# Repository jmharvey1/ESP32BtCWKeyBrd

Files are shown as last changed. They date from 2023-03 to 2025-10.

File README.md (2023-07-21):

# ESP32 Bluetooth CW Keyboard & Decoder
___

A VS Code/PlatformIO project, Using ESPIDF's framework.
  
This ham radio project uses a generic Bluetooth Keyboard to send Morse Code (cw), and now using the audio out of your RX can decode CW too.
<p align="center">  
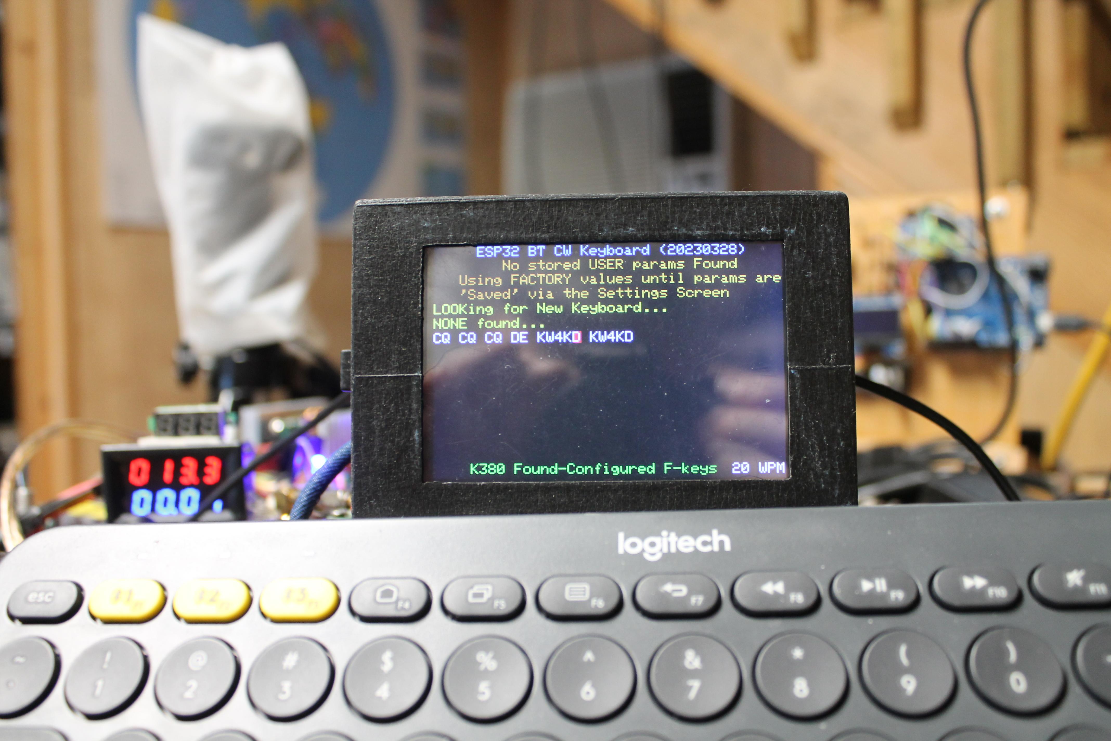
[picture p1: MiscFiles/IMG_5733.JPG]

</p>

<p dir="auto">For additional info, see YouTube video:
    <a href="https://youtu.be/Hb9m60LtSJw" rel="nofollow">https://youtu.be/Hb9m60LtSJw</a></p>

---
Main Hardware needed to replicate this project:
  
ESP32 WROOM dev board, (30 pin version)
  
3.5" TFT LCD Screen Display Module ILI9488 Board SPI Interface 480x320
  
Bluetooth Keyboard (Logitech K380, recommended)
  
___

Additional parts needed:
  
D4184 MOS FET (1)
  
HYDZ PIEZO Buzzer (1)

2n3904 (1)

2n3906 (1)

0.1ufd (3)

10ufd (1)
 
resistors 2.2K to 15K (4)
  
___
For those who want to bypass the source code, and just "flash" your ESP32, download the [ESPhomeFlasher](https://github.com/esphome/esphome-flasher/releases) and the [.bin file](https://github.com/jmharvey1/ESP32BtCWKeyBrd/blob/main/.pio/build/upesy_wroom/firmware.bin) found at these links.
  
Note: For me, using Linux Mint, the ESPhome-Flasher's 'Browse' button did NOT work. But placing the 'firmware.bin' file in the same folder as the flasher app, allowed me to just type the file name,"firmware.bin",
in the 'Firmware' cell.
  
A 2nd tip: Connect the ESP32 to your computer BEFORE launching the ESPhome-Flasher. 
___
A PCB for this project can be ordered from a board manufacturer, like [JLCPCB](https://jlcpcb.com/), using the gerber files found [Here](https://github.com/jmharvey1/ESP32BtCWKeyBrd/blob/main/MiscFiles/ESP32-BT-CW-KeyBrd_2023-03-16.zip).
  
A .PDF schematic for the PCB version of this project is [Here](https://github.com/jmharvey1/ESP32BtCWKeyBrd/blob/main/MiscFiles/ESP32-BT-CW-KeyBrd_Schematic.pdf)
  
If you have access to 3D printer, the [MiscFiles](https://github.com/jmharvey1/ESP32BtCWKeyBrd/tree/main/MiscFiles)
 folder contains “.stl” files for a simple case to host your completed project. 
___
Note: the PCB is currently not provisioned for the the decoder's audio input circuitry, nor is it documented in the MiscFiles folder.
But is super simple to add. It consists of pair of 10K voltage divider reisistors connected between gnd & the ESP32's 3.3V input, with the center tap connected to GPIO pin34 (ADC channel 6). A 0.1ufd DC blocking Capacitor is used to couple the external audio source (the RX's audio/speaker out) to GPIO pin 34.

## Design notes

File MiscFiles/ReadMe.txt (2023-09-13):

ESP32 Bluetooh KeyBoard user notes

***********************************************************************************
KeyBoard Encoder Notes:
Special Keys & their functions:
Keys that send special Morse Characters
1. “=”   <BT>
2. “+”	<KN>
3. ”>”	<AR>
4. ”<”	<AS>
5. ”%”	<SK>
6. All other unassigned keys (i.e. “{“, “]”,…) send 6 dits, CW error code

Special Functions:
1. cntrl+T	Generates continuous key down state. Press “cntrl+T” again (or another key) to stop.
2. Enter [pressed by itself] sends the "My Call" memory entry. (see settings screen)
3. “delete” Back space, to delete unsent buffered code.
4. Right Arrow	Same as F12.
5. Left Arrow Same as F1.  
6. Lshift+Enter” Send "Left Arrow" stored text plus Your call sign.
7. Cntrl+Enter” Send "Left Arrow" stored text.
8. "Esc"   Abort/dump outgoing text 	
10. Cntrl+S Go to settings Screen; Press Cntrl+S again to return to normal CW mode.(Note: No CW sent while in the "settings"mode); i.e., Default WPM. Call Sign, F2 memory
11. F1 Save up to ten characters (usually the DX call sign) to be sent when L. Shift (or Cntrl)+enter is pressed, Press F1 again to stop the "save"  mode (Note: status box in lower left is white while in "save" mode)
12. F2 Send stored F2 message
13. F3 Send stored F3 message
14. F4 Send stored F4 message
15. F12 suspend outgoing text; Press F12 again to resume sending outgoing text (Note: Status box is yellow while in "suspend" mode)

***********************************************************************************
CW Decoder Notes:
Special Keys & their functions:
1. Left & Rght Ctrl+d: index through CW decode modes
        Nrm (Normal)
        Bg1 (Bug 1)
        Bg2 (Bug 2)
        Bg3 (Bug 2 cootie keys)
2. Left Ctrl+f: index through select tone tune modes
        FF  (Fixed Frequency)
        AF  (Auto-Tune 500 to 900Hz)
3. Left Ctrl+G: index through 3 tone detect modes
        Nmf Fast Sample mode (4ms)
        Nms Slow Sample mode (8ms)
        Nmn Noisy signal mode (8ms sample period + damped Squech leveling)
4. Left Ctrl+P:  Plot On/off

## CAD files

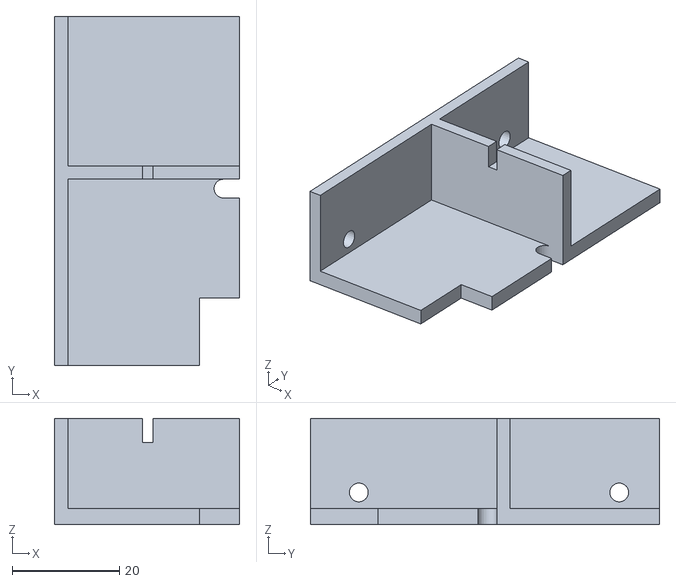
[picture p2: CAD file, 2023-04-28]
MiscFiles/ESP32BTKeyBrdSuprt.stl
34.5 x 65.0 x 19.8

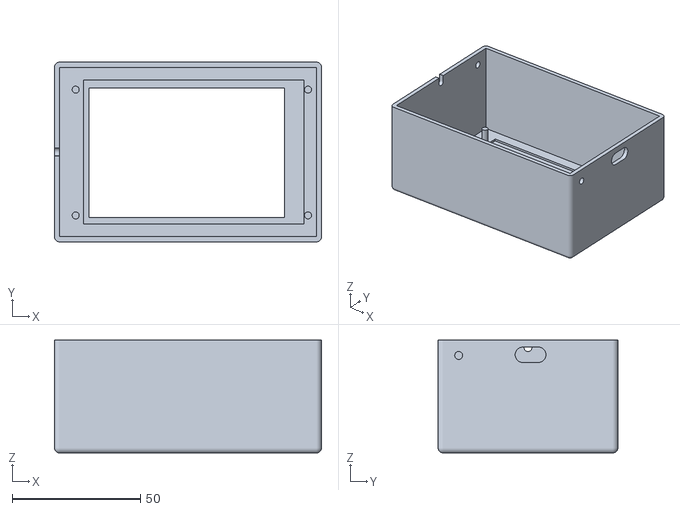
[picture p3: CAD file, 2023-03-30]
MiscFiles/ESP32BTKeyBrdCase.stl
104.0 x 70.0 x 44.0

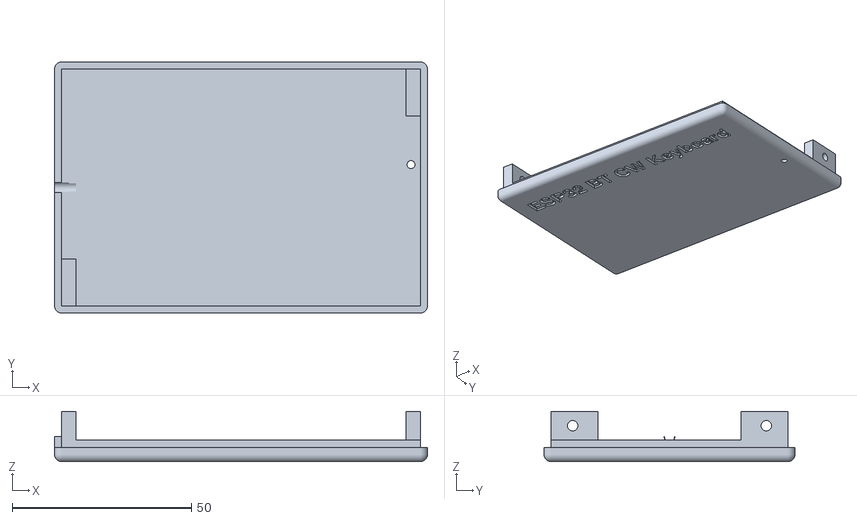
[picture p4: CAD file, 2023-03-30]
MiscFiles/ESP_BT_CW_KB_Backplate.stl
104.0 x 70.0 x 14.0

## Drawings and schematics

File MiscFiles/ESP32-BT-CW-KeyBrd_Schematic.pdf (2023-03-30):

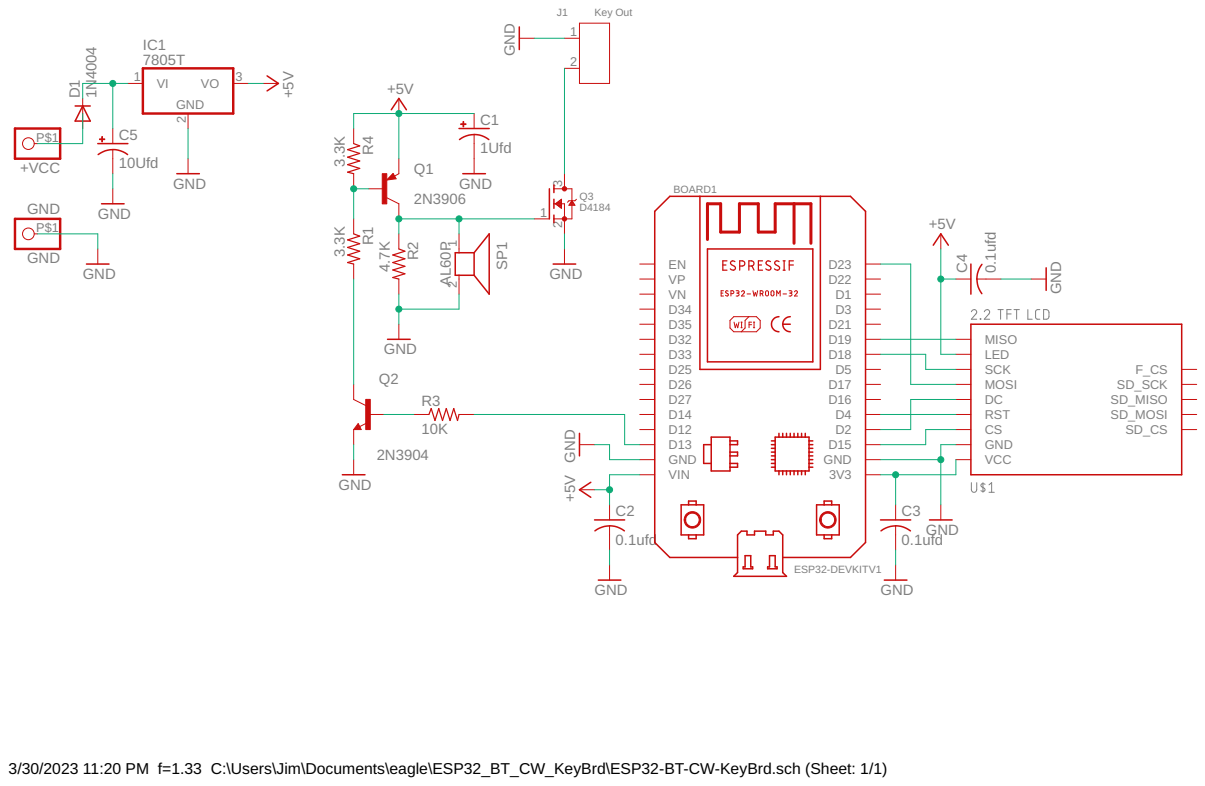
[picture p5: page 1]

3/30/2023 11:20 PM f=1.33 C:\Users\Jim\Documents\eagle\ESP32_BT_CW_KeyBrd\ESP32-BT-CW-KeyBrd.sch (Sheet: 1/1)

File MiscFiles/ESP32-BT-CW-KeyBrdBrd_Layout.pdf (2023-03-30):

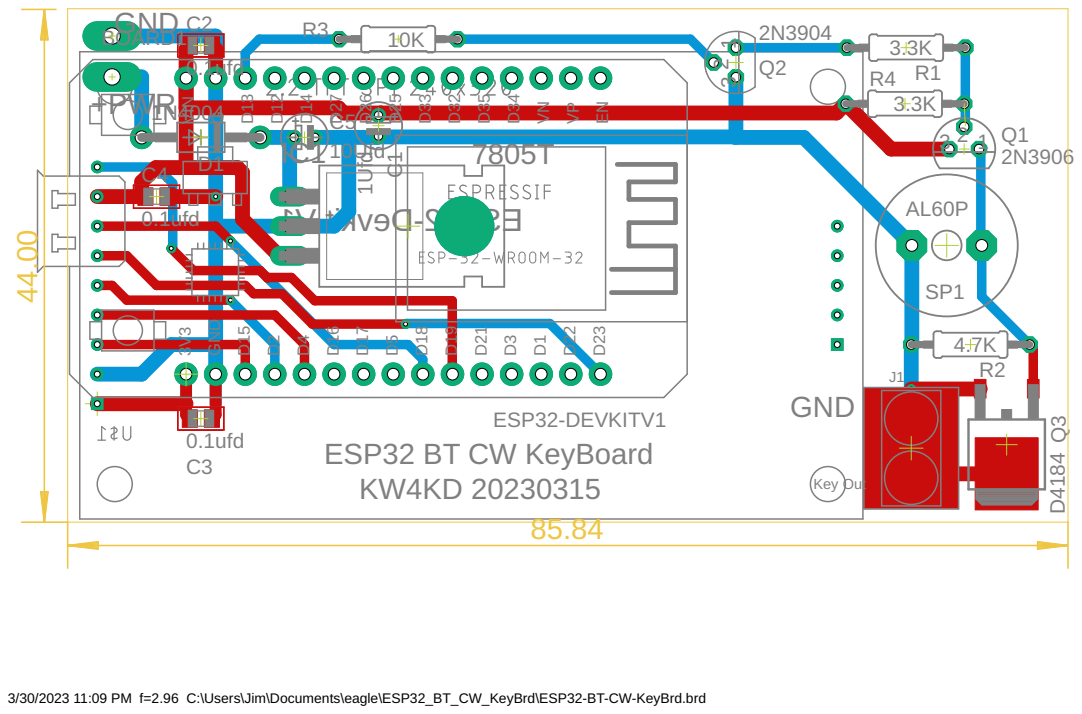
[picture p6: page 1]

3/30/2023 11:09 PM f=2.96 C:\Users\Jim\Documents\eagle\ESP32_BT_CW_KeyBrd\ESP32-BT-CW-KeyBrd.brd

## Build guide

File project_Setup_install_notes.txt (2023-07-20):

after copying files over,
run menuconfig,
& under Component config -> FreeRTos -> Kernel, enable configENABLE_BACKWARD_COMPATIBILITY
under component config -> bluetooth, check bluetooth
select/check Host Bluedroid-dual mode, & hid host
Controller (Enabled),
under Bluedriod options, check clasic bluetooth, & Classic BT hid
check Secure Simple Pairing, Bluetooth Low Energy
check IncludeGATT server module(GATTS)
check Enable BLE mult-connections. 
Leave all other selections to their default setting.
In the Dependant library 'TFT_eSPI', the following files have been modified to work in this hybrid enviroment:
1. User_Setup_Select.h
2. TFT_eSPI.h
3. TFT_eSPI.cpp
4. TFT_config. h
5. processors/TFT_eSPI32.h, ine 138, modified line to read "#include "SPIFFSJMH.h".
You can use MELD to see the differences. 
But probably easier to just copy these files from an already working project, with the same enviroment as this project
in the user_setup_select.h file, select the appropriate configuration for the display you're using. For SPI displays:
        #include <User_Setups/Setup42_ILI9341_ESP32.h>           // Setup file for ESP32 and SPI ILI9341 240x320
or
        #include <User_Setups/Setup21_ILI9488.h>           // Setup file for ESP32 and ILI9488 SPI bus TFT        
On TFTMsgBox.h, commnent or uncomment the "#define HiRes" (found @~ line 17) to match the resolution of the display being used.

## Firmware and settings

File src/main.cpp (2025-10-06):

/**
 * @file main.cpp
 * @brief ESP32 CW Decoder & Bluetooth Keyboard Main Application
 *
 * This file implements the main application logic for an ESP32-based CW (Morse code) decoder and Bluetooth keyboard interface.
 * It supports both Linux and Windows 10 environments and is designed to work with a TFT display (ILI9341 driver) and various
 * peripherals including ADC, Bluetooth HID keyboards, and FreeRTOS tasks.
 *
 * ## Features:
 * - Bluetooth keyboard pairing, scan, and event handling (supports Logitech K380 and others)
 * - Real-time CW decoding using Goertzel algorithm on ADC audio input
 * - Adjustable WPM (words per minute), auto-tune, and gain settings
 * - TFT display management for decoded text, status, and user interaction
 * - User-configurable memory messages (F2-F5), callsign, and settings stored in NVS
 * - Advanced Morse code parsing and error correction (AdvParser class)
 * - Multi-tasking using FreeRTOS for ADC processing, display updates, CW decoding, and post-processing
 * - Mutex and semaphore protection for shared resources
 * - Support for diagnostic and debug output
 * - Persistent user settings via NVS (Non-Volatile Storage)
 *
 * ## Main Components:
 * - **GoertzelHandler**: Processes ADC samples for tone detection and frequency measurement.
 * - **DisplayUpDt**: Updates the TFT display with decoded messages and status.
 * - **CWDecodeTask**: Main loop for CW decoding and error correction.
 * - **AdvParserTask**: Post-processing and advanced parsing of decoded Morse code.
 * - **ProcsKeyEntry**: Handles keyboard input, including special function keys and message sending.
 * - **NVS Read/Write Functions**: Manage persistent storage of user preferences and settings.
 * - **Timer ISRs**: Handle periodic display refresh and dot clock for outgoing Morse (CW) timing.
 *
 * ## Usage:
 * - On startup, initializes hardware, peripherals, and tasks.
 * - Pairs with a Bluetooth keyboard and waits for user input.
 * - Decodes incoming CW signals from ADC and displays results.
 * - Allows sending of pre-configured or custom messages via keyboard.
 * - User can access settings screen to configure preferences.
 *
 * ## Notable Definitions:
 * - `DF_t DFault`: Structure holding factory/user default settings.
 * - `TFTMsgBox tftmsgbx`: Handles display messaging.
 * - `CWSNDENGN CWsndengn`: Manages CW sending engine.
 * - `BTKeyboard bt_keyboard`: Bluetooth keyboard handler.
 * - `TxtNtryBox txtntrybox`: Text entry box for user input.
 *
 * ## Task Priorities:
 * - Goertzel Task: 5 (highest, for real-time ADC processing)
 * - CW Decode Task: 4
 * - Display Update Task: 3
 * - AdvParser Task: 2
 *
 * ## History:
 * - Extensive changelog documents ongoing improvements, bug fixes, and feature additions from 2020 through 2025.
 *
 * @author Jim (CW Decoder, ESP32 integration, enhancements)
 * @author Guy Turcotte (original BT-Keyboard code)
 * @copyright MIT License
 */
/* BT-Keyboard code (bt_keyboard.cpp) based on source code with the same file name &
   Copyright (c) 2020 by Guy Turcotte
   MIT License. Look at file licenses.txt for details.
*/
/*20230310 added logitech K380 configure function keys command */
/*20230317 added Memory F3 & F4 function keys */
/*20230328 moved to GitHub*/
/*20230405 reconfigued project files to run both on Linux & Windows 10*/
/*20230418 expanded send buffer from 160 to 400 charater (4 line to 10 dispaly lines)*/
/*20230429 Added code to CWSendEngn.cpp set character timing speed to a minimum of 15wpm*/
/*20230430 fixed crash issue related to changing speed while buffered code is being sent.*/
/*20230502 reworked WPM screen refresh & dotclk updated to timing period to avoid TFT display crashes.*/
/*20230503 Added code to bt_keyboard.cpp test for 'del' key presses an convert to hex code 0x2A*/
/*20230507 Reversed bavior of "Up" & "Down" Arrow keys & corrected dotclock startup timing to actually match the User stored WPM setting*/
/*20230607 DcoderCW.cpp CLrDCdValBuf() added other buffers & codevals to reset to stop decode artifacts of what the CWgen code was making during user send */
/*20230608 Enabled AutoTune indecoder default configuration */
/*20230609 Added code to the KEYISR (DcodeCW.cpp) to improve recovery/WPM tracking from slow to fast CW */
/*20230610 Remove '@'from the decoder dictionary */
/*20230615 reworked Goertzel.cpp & DcodeCW.cpp to better track the incoming WPM speed of the received station plus slight improvement in decoding CW @ > 35WPM As well at lower SNRs */
/*20230616 Added decoder mode & autotune to NVS eeprom; reworked startup (app_main) sequence to reduce crashes during 1st time pairing process */
/*20230617 To support advanced DcodeCW "Bug" processes, reworked dispMsg2(void) to handle ASCII chacacter 0x8 "Backspace" symbol*/
/*20230624 Minor tweaks to tone detect code & installed mutexs in bletooth callback to try to better manage SPI resource calls*/
/*20230701  Reworked Goertzel tone detection & added adjustable glitch detection; Also reworked Goertzel sample count code */
/*20230707 Added shortcuts (left/right Ctrl+g) user cntrolled gain setting; and reworked Glitch detection*/
/*20230708 reworked Glitch detection by adding a front end average keydown section to the tone detect routine; it now sets the glitch inteval*/
/*20230711 minor tweaks to concatenate processes (DcodeCW.cpp) to imporve delete character managment */
/*20230715 minor tweaks */
/*20230719 added "noreturn" patch to crash handler code and removed printf() calls originally in IRAM_ATTR DotClk_ISR(void *arg)*/
/*20230721 Moved project to github*/
/*20230727 Fixed Crash issue related to BT Keyboard sending corrupted keystroke data; fix mostly containg bt_keyboard.hid callback code*/
/*20230727 Reworked pairing code & mail code to avoid watchdog timer crashes*/
/*20230728 reworked code to improve pairing of multiple keyboard */
/*20230729 added calls to DcodeCW SetLtrBrk() & chkChrCmplt() to ensure that the letter break gets refreshed with each ADC update (i.e., every 4ms)*/
/*20230730 blocked the gudsig function to imporve noisy signal decoding */
/*20230731 Now launching the chkChrCmplt() strickly from goertzel/Chk4KeyDwn() task/routine*/
/*20230801 Added Short/Long (4ms/8ms) sample interval; User selectable via Ctrl+g */
/*20230804 Minor timing tweaks to  DecodeCW & Goertzel code*/
/*20230807 rewrote sloppy string check code for ESP32; See CcodeCW.cpp */
/*20230810 beta fix for crash linked to 1st time connection to previously 'paired keyboard. Requires stopping ADC sampling during the 'open' Keyboard event*/
/*20230811 beta2 fix for crash linked to 1st time connection to previously 'paired keyboard. Requires stopping ADC sampling during the 'open' Keyboard event*/
/*20230812 fix crash when using backspace key to delete unsent text */
/*20230814 changed ltrbrk timing for slow speed Bg2 mode */
/*20230815 revised Bg2 timing & rewote ltrbreak debugging output code */
/*20230818 fixed pairing crash linked to display SPI conflcit during BT pairing event */
/*20230916 Changed Auto-tune method; & reworked tone level detection; Added 3rd gain mode/setting */
/*20230918 Refined Auto-tune code; added autogain setting shift from slow to fast; added StrechLtrcmplt() to DcodeCW.cpp to better manage letterbreak detection */
/*20231103 reworked  DcodeCW.cpp, dit/dah decision tests & in Goertzel reworked auotsample rate detection code */
/*20231215 added DblChkDitDah() to DcodeCW.cpp, to further improve dit/dah decision tests */
/*20231217 reworked file references to match framework-espidf @ 3.50100.0 (5.1.0) */
/*20231221 minor tweek to DblChkDitDah (DeCodeCW.cpp) routine to improve resolving dits from dahs*/
/*20231229 More tweaks to bug2 letter break code (DeCodeCW.cpp)*/
/*20240101 More tweaks to bug2 letter break code (DeCodeCW.cpp)*/
/*20240103 Modified extented sysmbolset timing to only effect Bg1 mode*/
/*20240110 Added Advparser Class */
/*20240112 Continued development of Advparser Class */
/*20240115 Continued development/enhancement of Advparser Class */
/*20240117 added Dcode4Dahs() to AdvParser class; parses 4 dahs into "TO" or "OT", "MM" also a possible result */
/*20240119 added test for paddle/keybrd by finding all dahs have the same interval;*/
/*20240120 reworked DitDahBugTst() method to better detect bug vs paddle/keyboard signals plus minor tweaks to bug rule set*/
/*20240122 revised AdvParser.cpp DitDahSplitVal averaging algorithm to be based on last 30 symbol set elements*/
/*20240123 AdvParser.cpp - Added letterbrk bug test "2", to look for lttrbk based on "long" dah*/
/*20240124 DcodeCW.cpp added requirement that Key up & down arrays match in length before attempting to do a post reparse of the last word captured*/
/*20240129 AdvParser.cpp - improved method for calculating DitIntrvlVal + other tweaks to bug parsing rules*/
/*20240201 AdvParser.cpp - Added Straight Key Rule Set & Detection; Revised Bug1 RS dit & dah runs parsing*/
/*20240202 AdvParser.cpp - Added Bg1SplitPt & refined Bug1 "Dah run" code*/
/*20240203 Added initialization values to AdvParser to imporve 1st decode/parsing results*/
/*20240204 added GetState method to CWSndEngn class; primarily to notify decoder/Goertzl side to go into 'standby/sleep' mode*/
/*20240205 added WrdBrkVal property Advparser Class + changes to Bug1 & DitDahBugTst*/
/*20240206 added StrchdDah property to Advparser Class*/
/*20240207 ammended 'Advparser.AdvSrch4Match' method for setting up 'follow on' search*/
/*20240208 AdvParser.cpp, reworked 'LstLtrBrkCnt' management to better track the number of keyevents since the last letterbreak event */
/*20240210 created new class method 'Advparser.SrchAgn()'*/
/*20240211 Made chnges to AdParser.cpp, mainly to align dit/dah decision points with the ruleset in play */
/*20240215 AdParser.cpp - More minor tweaks to Bug1 Rule set & DitDahBugTst()*/
/*20240216 AdParser.cpp - Added 'FixClassicErrors()' method*/
/*20240220 AdParser.cpp - added 'SloppyBgRules()' method. Plus numerous changes to integrate this rule set into the existing code */
/*20240223 numerous 'tweaks' to AdParser.cpp, mostly to better delineate between different key types*/
/*20240225 AdParser.cpp - more 'tweaks' to bug2 & sloppybug rule sets */
/*20240225 setup post parsing to run as a task (AdvParserTask)*/
/*20240227 reworked AdvParserTask() & setup to run on core 1; reworked AdvParser.cpp - GetMsgLen(void), FixClassicErrors(void), & SloppyBgRules(int& n)*/
/*20240301 AdParser.cpp -Changed BG2 dah run to detect letterbreak on UnitIntvrlx2r5; chages to SetSpltPt()*/
/*20240304 Reworked deployment of mutex to reduce code crashes linked to keyboard entries*/
/*20240307 AdParser.cpp Added SrchEsReplace() function & and simplified the code in FixClassicErrors()*/
/*20240309 AdParser.cpp - Moved straight key test ahead of sloppy test*/
/*20240309 AdParser.cpp - Mostly tweaks in FixClassicErrors() code */
/*20240313 AdParser.cpp - rewrote FixClassicErrors() to sequence through SrchRplcDict[] array to test for mangled character strings */
/*20240315 AdvParser.cpp - rewrote FixClassicErrors() to use a 'for' loop to sequence through the SrchRplcDict[]*/
/*20240317 changed task management mainly through priority level assignments; reworked AdParser.SetSpltPt() method to better handle cootie type keying*/
/*20240322 expanded SrchRplcDict[] to 192 entries */
/*20240323 expanded SrchRplcDict[] to 212 entries*/
/*20240330 expanded SrchRplcDict[] to 289 entries*/
/*20240405 expanded SrchRplcDict[] to 329 entries*/
/*20240408 expanded SrchRplcDict[] to 346 entries*/
/*20240411 expanded SrchRplcDict[] to 400 entries*/
/*20240414 expanded SrchRplcDict[] to 413 entries*/
/*20240420 expanded SrchRplcDict[] to 472 entries*/
/*20240427 expanded SrchRplcDict[] to 526 entries*/
/*20240502 added entries 527 - 586 to  SrchRplcDict[] (superslopy) */
/*20240504 expanded SrchRplcDict[] to 634 entries*/
/*20240518 expanded SrchRplcDict[] to 682 entries*/
/*20240519 AdvParser.cp Added glitch detection*/
/*20240522 Goertzel.cpp, added auto glitch detection,to support post parser (AdvParser.cpp)*/
/*20240601 Minor tweaks to AdvParser.cpp to improve rule set selection & adds SrchRplcDict[]*/
/*20240608 Expanded SrchRplcDict[] to 731 entries*/
/*20250930 restructed to work with framework-espidf@~3.50202.0 */
/*20251006 bt_keyboard.cpp reworked keyboard pairing & reconnect */

#include "sdkconfig.h" //added for timer support
#include "globals.h"
#include "main.h"
#include "bt_keyboard.hpp"
#include <esp_log.h>
#include <iostream>
//#include "esp32-hal-spi.h"
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
void app_main()
{
  /*uncomment the following for diagnostic testing of host HID connection/pairing to keyboard*/
  // Exmpl_main();
  // while(1){
  //   vTaskDelay(1000 / portTICK_PERIOD_MS);
  // }
  ModeCnt = 0;
  static const char *TAG = "TASK Config";
  // Configure pin
  gpio_config_t io_conf;
  io_conf.intr_type = GPIO_INTR_DISABLE;
  io_conf.mode = GPIO_MODE_OUTPUT;
  io_conf.pin_bit_mask = (1ULL << KEY);
  io_conf.pull_down_en = GPIO_PULLDOWN_DISABLE;
  io_conf.pull_up_en = GPIO_PULLUP_DISABLE;
  gpio_config(&io_conf);
  digitalWrite(KEY, Key_Up); // key 'UP' state
  state_que = xQueueCreate(state_que_len, sizeof(uint8_t));
  /*create DisplayUpDate Task*/
  xTaskCreatePinnedToCore(DisplayUpDt, "DisplayUpDate Task", 8192, NULL, 3, &DsplUpDtTaskHandle, 0);
  vTaskSuspend( DsplUpDtTaskHandle);

  /*Selected 2092 based on results found by using uxTaskGetStackHighWaterMark( NULL ) in AdvParserTask*/
  xTaskCreatePinnedToCore(
      AdvParserTask, /* Function to implement the task */
      "AdvParser Task", /* Name of the task */
      4096,  /* Stack size in words */
      NULL,  /* Task input parameter */
      2,  /* Priority of the task */
      &AdvParserTaskHandle,  /* Task handle. */
      1); /* Core where the task should run */
  if (AdvParserTaskHandle == NULL)
    ESP_LOGI(TAG, "AdvParser Task handle FAILED");

  vTaskSuspend( AdvParserTaskHandle );
  
  xTaskCreatePinnedToCore(
      CWDecodeTask, /* Function to implement the task */
      "CW Decode Task", /* Name of the task */
      8192,  /* Stack size in words */
      NULL,  /* Task input parameter */
      4,  /* Priority of the task */
      &CWDecodeTaskHandle,  /* Task handle. */
      0); /*Core 0 or 1 */
  
  if (CWDecodeTaskHandle == NULL)
    ESP_LOGI(TAG, "CW Decoder Task handle FAILED");

  xTaskCreate(GoertzelHandler, "Goertzel Task", 8192, NULL, 5, &GoertzelTaskHandle); // priority used to be 3
  if (GoertzelTaskHandle == NULL)
    ESP_LOGI(TAG, "Goertzel Task Task handle FAILED");

  /*Setup Software Display Refresh/Update timer*/
  DisplayTmr = xTimerCreate(
      "Display-Refresh-Timer",
      33 / portTICK_PERIOD_MS,
      pdTRUE,
      (void *)1,
      DsplTmr_callback);

  memset(result, 0xcc, (SOC_ADC_DIGI_RESULT_BYTES * Goertzel_SAMPLE_CNT)); // 1 byte for the channel # & 1 byte for the data
  mutex = xSemaphoreCreateMutex();
  // ADC_smpl_mutex = xSemaphoreCreateMutex();

  /*setup Hardware DOT Clock timer & link to timer ISR*/
  const esp_timer_create_args_t DotClk_args = {
      .callback = &DotClk_ISR,
      .arg = NULL,
      .dispatch_method = ESP_TIMER_ISR,
      .name = "DotClck"};

  ESP_ERROR_CHECK(esp_timer_create(&DotClk_args, &DotClk_hndl));

  
  /* The timer has been created but is not running yet */
intr_matrix_set(xPortGetCoreID(), ETS_TG0_T1_LEVEL_INTR_SOURCE, 26); // display

  // ESP_LOGI(TAG, "Start DotClk interrupt Config");
  // ESP_ERROR_CHECK(esp_intr_alloc(ETS_TG0_T1_LEVEL_INTR_SOURCE, ESP_INTR_FLAG_LEVEL3, DotClk_ISR, DotClk_args.arg, NULL));
  // ESP_LOGI(TAG, "End DotClk interrupt Config");

  ///////////////////////////////////////////////////////////////////////////////////////////////////////
 ESP_INTR_ENABLE(26); // display

  // /* Start the timer dotclock (timer)*/
  // ESP_ERROR_CHECK(esp_timer_start_periodic(DotClk_hndl, 60000)); // 20WPM or 60ms

  
  // To test the Pairing code entry, uncomment the following line as pairing info is
  // kept in the nvs. Pairing will then be required on every boot.
  // ret = nvs_flash_init();
  // ESP_ERROR_CHECK(nvs_flash_erase());
  ret = nvs_flash_init();
  if ((ret == ESP_ERR_NVS_NO_FREE_PAGES) || (ret == ESP_ERR_NVS_NEW_VERSION_FOUND))
  {
    ESP_ERROR_CHECK(nvs_flash_erase());
    ret = nvs_flash_init();
  }
  ESP_ERROR_CHECK(ret);

  /*Initialize display and load splash screen*/
  tftmsgbx.InitDsplay();
  sprintf(Title, " ESP32 CW Decoder & Keyboard (%s)\n", RevDate); // sprintf(Title, "CPU CORE: %d\n", (int)xPortGetCoreID());
  tftmsgbx.dispMsg(Title, TFT_SKYBLUE);

  /* test/check NVS to see if user setting/param have been stored */
  uint8_t Rstat = Read_NVS_Str("MyCall", DFault.MyCall);
  if (Rstat != 1)
  {
    /*No settings found; load factory settings*/
    sprintf(DFault.MyCall, "%s", MyCall);
    sprintf(DFault.MemF2, "%s", MemF2);
    sprintf(DFault.MemF3, "%s", MemF3);
    sprintf(DFault.MemF4, "%s", MemF4);
    sprintf(DFault.MemF5, "%s", MemF5);
    DFault.DeBug = DeBug;
    DFault.WPM = CWsndengn.GetWPM();
    DFault.ModeCnt = ModeCnt;
    DFault.AutoTune = AutoTune;
    DFault.TRGT_FREQ = (int)TARGET_FREQUENCYC;
    DFault.Grtzl_Gain = Grtzl_Gain;
    DFault.SlwFlg = SlwFlg;
    DFault.NoisFlg = NoisFlg;
    sprintf(Title, "\n        No stored USER params Found\n   Using FACTORY values until params are\n   'Saved' via the Settings Screen\n");
    tftmsgbx.dispMsg(Title, TFT_ORANGE);
    bt_keyboard.trapFlg = false;
  }
  else
  {
    /*found 'mycall' stored setting, go get the other user settings */
    Rstat = Read_NVS_Str("MemF2", DFault.MemF2);
    Rstat = Read_NVS_Str("MemF3", DFault.MemF3);
    Rstat = Read_NVS_Str("MemF4", DFault.MemF4);
    Rstat = Read_NVS_Str("MemF5", DFault.MemF5);
    Rstat = Read_NVS_Val("DeBug", DFault.DeBug);
    Rstat = Read_NVS_Val("WPM", DFault.WPM);
    Rstat = Read_NVS_Val("ModeCnt", DFault.ModeCnt);
    Rstat = Read_NVS_Val("TRGT_FREQ", DFault.TRGT_FREQ);
    int intGainVal; // uint64_t intGainVal;
    Rstat = Read_NVS_Val("Grtzl_Gain", intGainVal);
    DFault.Grtzl_Gain = (float)intGainVal / 10000000.0;
    int strdAT;
    Rstat = Read_NVS_Val("AutoTune", strdAT);
    DFault.AutoTune = (bool)strdAT;
    Rstat = Read_NVS_Val("SlwFlg", strdAT);
    DFault.SlwFlg = (bool)strdAT;
    Rstat = Read_NVS_Val("NoisFlg", strdAT);
    DFault.NoisFlg = (bool)strdAT;
    /*pass the decoder setting(s) back to their global counterpart(s) */
    AutoTune = DFault.AutoTune;
    SlwFlg = DFault.SlwFlg;
    NoisFlg = DFault.NoisFlg;
    ModeCnt = DFault.ModeCnt;
    DeBug = DFault.DeBug;
    TARGET_FREQUENCYC = (float)DFault.TRGT_FREQ;
    Grtzl_Gain = DFault.Grtzl_Gain;
  }
  /* Start the Display timer */
  xTimerStart(DisplayTmr, portMAX_DELAY);
  vTaskResume( DsplUpDtTaskHandle);
  // CWsndengn.RfrshSpd = true;
  // CWsndengn.ShwWPM(DFault.WPM); // calling this method does NOT recalc/set the dotclock & show the WPM
  // CWsndengn.SetWPM(DFault.WPM); // 20230507 Added this seperate method call after changing how the dot clocktiming gets updated

  InitGoertzel();
  vTaskDelay(100 / portTICK_PERIOD_MS);
  bt_keyboard.inPrgsFlg = false;
  /*start bluetooth pairing/linking process*/
  if (bt_keyboard.setup(pairing_handler))
  {                             // Must be called once
    printf("START SCAN\n");
    bt_keyboard.devices_scan(3); // Required to discover new keyboards and for pairing
                                // Default duration is 3 seconds
    printf("EXIT SCAN\n");                            
  }
  else
  {
    sprintf(Title, "\n*******  RESTART!  ******\n** NO KEYBOARD PAIRED ***");
    tftmsgbx.dispMsg(Title, TFT_RED);
    while (true)
    {
      /*do nothiing*/
      delay(20);
    }
  }
  /*initialize & start continuous DMA ADC conversion process*/
  continuous_adc_init(channel, sizeof(channel) / sizeof(adc_channel_t), &adc_handle);
  //xTaskCreate(GoertzelHandler, "Goertzel Task", 8192, NULL, 5, &GoertzelTaskHandle); // priority used to be 3

  adc_continuous_evt_cbs_t cbs = {
      .on_conv_done = s_conv_done_cb,
  };
  ESP_ERROR_CHECK(adc_continuous_register_event_callbacks(adc_handle, &cbs, NULL));
  ESP_ERROR_CHECK(adc_continuous_start(adc_handle));
  adcON = true;
  xTaskNotifyGive(CWDecodeTaskHandle);
  vTaskDelay(200 / portTICK_PERIOD_MS);
  
  ESP_LOGI(TAG, "Start DotClk interrupt Config");
  ESP_ERROR_CHECK(esp_intr_alloc(ETS_TG0_T1_LEVEL_INTR_SOURCE, ESP_INTR_FLAG_LEVEL3, DotClk_ISR, DotClk_args.arg, NULL));
  ESP_LOGI(TAG, "End DotClk interrupt Config"); 
 /* Start the timer dotclock (timer)*/
  ESP_ERROR_CHECK(esp_timer_start_periodic(DotClk_hndl, 60000)); // 20WPM or 60ms
  CWsndengn.RfrshSpd = true;
  CWsndengn.ShwWPM(DFault.WPM); // calling this method does NOT recalc/set the dotclock & show the WPM
  CWsndengn.SetWPM(DFault.WPM); // 20230507 Added this seperate method call after changing how the dot clocktiming gets updated

  

  /* main CW keyboard loop*/
  
  while (true)
  {
#if 1 // 0 = scan codes retrieval, 1 = augmented ASCII retrieval
    /* note: this loop only completes when there is a key entery from a paired/connected Bluetooth Keyboard */

    vTaskDelay(1); // give the watchdogtimer a chance to reset
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

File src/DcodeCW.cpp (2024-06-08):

/*Msgbuf
 * DcodeCW.cpp
 *
 *  Created on: Mar 28, 2021
 *      Author: jim
 * 20221020 changed the interval measuring clock from HAL_GetTick() timer5, for improved timing measurements
 * 20221025 made changes to timing/parsing routines to improve Bug3 (cootie) decoding
 * 20230609 Added code to the KEYISR to improve recovery/WPM tracking from slow to fast CW
 * 20230617 To support advanced DcodeCW "Bug" processes, reworked dispMsg(char Msgbuf[50]) to handle "delete" character condition
 * 20230711 minor tweaks to concatenate processes to improve delete character managment
 * 20230729 Changed letter break scheme to now be driven from the Goertzel side of the house
 * 20230731 Now launching the chkChrCmplt() strickly from goertzel/Chk4KeyDwn() task/routine
 * 20230807 rewrote sloppy string check code for ESP32; Now using a small buffer,"DcddChrBuf" in place of the pagebuffer used in the STM serries
 * 20230815 revised Bg2 timing & rewote ltrbreak debugging output code
 * 20230913 increased eeettt count before WPM reset.
 * 20231104 worked on bug3 parsing code; some improvement; but still more to be done
 * 20231221 minor tweek to DblChkDitDah routine to improve resolving dit from dah
 * 20231229 More tweeks to bug2 letter break code
 * 20231231 tweeks related to new 8ms/4ms sampling method
 * 20240103 Modified extented sysmbolset timing to only effect Bg1 mode
 * 20240114 Changed AdvPaser linking to handle post processed string overwrites that were longer than the origimal text
 * 20240116 Expanded time intervsl storage from 16 interval to 24 using MaxIntrvlCnt to support senders who think its ok to send more than five symbols W/o a letter break
 * 20240117 Added AdvParser detected keymode to dispaly status line
 * 20240124 added requirement that Key up & down arrays match in length before attempting to do a post reparse of the las word captured
 * 20240420 added auto word break timing 'wrdbrkFtcr' ; added auto word break timing 'wrdbrkFtcr' (AdvParser/DcodeCW)
 * 20240522 added auto glitch detection to support post parser (AdvParser.cpp) 
 *   */
 

// #include <SetUpCwDecoder.h>
// #include "main.h" // removed this reference for ESP32 version
#include "DcodeCW.h"
#include "Goertzel.h"

// #include "TchScrnCal.h"
#include "Arduino.h" //For ESP32, may not need this reference, since timr5 count calls are replaced with ESP32 equivalent
// #include "SerialClass.h"
#define MaxIntrvlCnt 24
bool DbgWrdBrkFtcr = false;//when 'true', reports "WrdBrkFtcr" to usb serial port/monitor
int ShrtBrk[10];
int charCnt = 0;
int shwltrBrk = 0;
int msgcntr = 0;
int badCodeCnt = 0;
int dahcnt = 0;
int MsgChrCnt[2];
int ltrCmplt = -2200; // letter complete false;  used in plot mode, to show where/when letter breaks are detected
volatile int TimeDat[MaxIntrvlCnt];
int Bitpos = 0;
int badKeyEvnt = 0;
int DeleteID = 0;
uint8_t LclKeyState; // local copy of the current keystate as passed from the Goertzel routine; 0 = Keydown; 1 = Keyup
// int px = 0; //mapped 'x' display touch value
// int py = 0; //mapped 'y' display touch value
int displayW = 320;
int LineLen = 27; // max number of characters to be displayed on one line
// int btnPrsdCnt = 0;
int statsMode = 0;
int textSrtX = 0;
int textSrtY = 0;
//int cnt = 0; // used in scrollpage routine
//int curRow = 0;
int offset = 0;
int LtrCntr = 0;
int OldLtrPntr = 0;
int unsigned ClrBtnCnt = 0;
int unsigned ModeBtnCnt = 0;
int ModeCnt = 0; // used to cycle thru the 4 decode modes (norm, bug1, bug2, bug3)

int TEcnt = 0;
int BadDedSpceCnt = 0;

int ylo = 295;	// button touch reading 3.5" screen
int yhi = 320;	// button touch reading 3.5" screen
int Stxl = 0;	// Status touch reading 3.5" screen
int Stxh = 140; // 150; //Status touch reading 3.5" screen
int bxlo = 155; // button touch reading 3.5" screen
int bxhi = 240; // button touch reading 3.5" screen
int gxlo = 240; // button touch reading 3.5" screen
int gxhi = 325; // button touch reading 3.5" screen
/*Tone Speed Button */
int Sbxlo = 326; // button touch reading 3.5" screen
int Sbxhi = 400; // button touch reading 3.5" screen
// int CPL = 40; //number of characters each line that a 3.5" screen can contain
// int row = 10; //number of uable rows on a 3.5" screen
int fontH = 16;
int fontW = 12;
int cursorY = 0;
int cursorX = 0;
int wpm = 0;
int lastWPM = 0;
int Pstate = 0;
// int RfshFlg = 0; //no longer needed here; now done in Goertzel.cpp
// int DeBug = 0;
int TDBptr = 0;

volatile int TimeDatBuf[24];

char newLine = '\n';
char DeBugMsg[150];
char DcddChrBuf[10]; //holds the last 10 decoded & DIsplayed characters; Pimarily used to look/test for common slopy sending strings
char Msgbuf[50];
char LstPstdchar[2]; // used for diagnostic testing only
char P[13];
char PrntBuf[150];
//char curChar = 0;// 20240227 moved this to be a global variable so that it can also be tested in the advparser task 
/*the following vairables were created for the AutoMode detector*/
uint16_t KeyUpIntrvls[IntrvlBufSize];
uint16_t KeyDwnIntrvls[IntrvlBufSize];
int KeyUpPtr = 0;
int KeyDwnPtr = 0;

// DeBug Character buffer to compare original Decode Text Vs AdvParser text
char LtrHoldr[30];
int LtrPtr = 0;
int WrdChrCnt = 0;
//AdvParser advparser; // create/instantuate the AdvParser Object/Class
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

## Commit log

2023-03-28 Initial Project Upload
    [partitions.csv]
2023-03-30 Added Schematic & PCB info/links
    [ESP32BTKeyBrdCase.stl, ESP_BT_CW_KB_Backplate.stl]
2023-04-28 Add PCB support plate to 3d Print Case collection
    [ESP32BTKeyBrdSuprt.stl]
2023-04-29 Added reference 3D printer files
2023-04-29 Corrected reference to 3D print files
2023-04-30 Add F5 Memory; updating DotClock w/ current WPM
2023-05-02 20230502 reworked WPM screen refresh code & updates to dotclk timing interval to avoid TFT display crashes.
    [CWSndEngn.cpp, main.cpp]
2023-05-03 Fixed "del' key codemapping issue
    [bt_keyboard.cpp, main.cpp]
2023-05-07 Fixed WPM setting on startup not locking in
    [bt_keyboard.cpp, main.cpp]
2023-07-20 Major Update. Added code to both Send & Decode CW.
    [partitions.csv]
2023-07-22 tweaks to source code comments & enabled auto-reboot on crash
    [DcodeCW.cpp]
2023-07-27 fixed crash linked to KB sending corrupt keystroke data
    [DcodeCW.cpp, Goertzel.cpp, bt_keyboard.cpp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]
2023-07-28 reworked pairing code & mail code to avoid watchdog timer crashes
    [bt_keyboard.cpp, main.cpp]
2023-07-29 linked letterbreak calcs directly to ADC updates Imporved pairing multiple KBs Added trap for K380 corrupt keystrokes
2023-07-31 Fixed random doubles in CW decoder
    [DcodeCW.cpp, main.cpp]
2023-08-01 Added Short/Long (4ms/8ms) sample interval; User selectable via Ctrl+g
    [DcodeCW.cpp, Goertzel.cpp, bt_keyboard.cpp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]
2023-08-07 modified sloppy string detect code
    [DcodeCW.cpp, Goertzel.cpp, main.cpp]
2023-08-11 Stop ADC sampling on 1st connection to paired Kbrd
2023-08-11 2nd attempt to fix crash while connecting to a 'paired' kerbord
    [bt_keyboard.cpp, main.cpp]
2023-08-11 Both Left & Right ctrl+g now set sample interval
2023-08-13 Fixed Backspace crash linked to shared SPI
    [main.cpp]
2023-08-19 code changes to fix pairing crash
    [main.cpp]
2023-12-17 reworked file references to match framework-espidf @ 3.50100.0
    [main.cpp]
2024-01-01 New 4ms updates w/ 8ms sample sets, plus related keystate detection tweeks
2024-01-21 reworked DitDahBugTst() method to better detect bug vs paddle
    [main.cpp]
2024-01-23 AdvParser.cpp - Added letterbrk bug test "2", to look for lttrbk based on "long" dah
    [main.cpp]
2024-01-29 AdvParser.cpp - improved method for calculating DitIntrvlVal + other tweaks to bug parsing rules
    [main.cpp]
2024-02-02 Beta Ver; Added Bg1SplitPt & refined Bug1 "Dah run" code
    [main.cpp]
2024-02-06 added WrdBrkVal property Advparser Class + changes to Bug1 & DitDahBugTst
    [main.cpp]
2024-02-08 reworked 'LstLtrBrkCnt' to better track number of keyevents since last letterbreak
    [main.cpp]
2024-02-15 AdParser.cpp - More minor tweeks to Bug1 Rule set & DitDahBugTst()
    [DcodeCW.cpp, main.cpp]
2024-02-17 AdParser.cpp - Added 'FixClassicErrors()' method
    [DcodeCW.cpp, main.cpp]
2024-02-25 AdParser.cpp - more 'tweaks' to bug2 & sloppybug rule sets
    [main.cpp]
2024-03-04 Reworked deployment of mutex to reduce code crashes linked to keyboard entries
    [CWSndEngn.cpp, main.cpp]
2024-03-10 AdParser.cpp - Mostly tweaks in FixClassicErrors() code
    [main.cpp]
2024-03-14 AdParser.cpp - rewrote FixClassicErrors() to use SrchRplcDict[]
    [DcodeCW.cpp, main.cpp]
2024-05-19 AdvParser.cp Added glitch detection
    [main.cpp]
2024-05-22 Goertzel.cpp, added auto glitch detection,to support post parser (AdvParser.cpp)
    [DcodeCW.cpp, Goertzel.cpp, main.cpp]
2025-10-06 reworked keyboard pairing & reconnect process
    [ESP32BTKeyBrdCase.stl, ESP32BTKeyBrdSuprt.stl, ESP_BT_CW_KB_Backplate.stl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]
